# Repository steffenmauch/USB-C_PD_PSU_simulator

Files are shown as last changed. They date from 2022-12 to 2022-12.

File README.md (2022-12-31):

# USB-C_PD_PSU_simulator

USB-C PD power supply simulator based on STUSB4710 with CP2112 USB/I2C interface chip

### Introduction

- USB-C power delivery powers supply simulator based on STUSB4710
- can be used to simulated non conformant power supplies
- e.g. output different voltage than the one being negotiated
- manipulate offered contracts to simulate specific power supplies
- layout and schematic has been realized with KiCad 6
- correspondig software is written with python 3
- communication with STUSB4710 is realized with SiLabs 2112 USB to I2C/SMBUS interface chip

### Hardware Setup

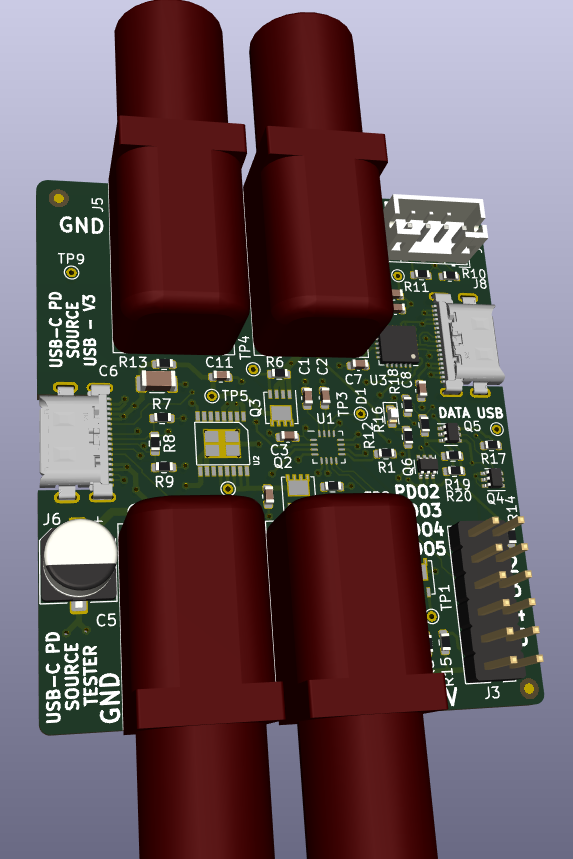
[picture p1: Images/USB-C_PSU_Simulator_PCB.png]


Find schematic as PDF [here](./ECAD/USB-C_PSU_Simulator.pdf)

### Usage
- install python3 if not already installed; e.g. https://winpython.github.io/ for Windows users
- download from www.silabs.com the driver containing the files 'SLABHIDDevice.*' and 'SLABHIDtoSMBus.*' (extension .dll for Windows)
- copy both files into 'Software' subdirectory
- execute e.g. 'python configSTUSB4710.py' in the 'Software' subdirectory
```
python configSTUSB4710.py
usage: configSTUSB4710.py [-h] [-r] [--setToleranceVBUS [0-15]] [--setPDO SETPDO [SETPDO ...]] [--printRDO] [--printPDO] [--printNVM] [--printToleranceVBUS] [--printVBUSControl] [--printPortStatus]
                          [--printSTUSBVersion] [-v]

Configure STUSB4710 for USB-C PD power supply simulation; (c) 12/2022 Steffen Mauch; MIT license

optional arguments:
  -h, --help            show this help message and exit
  -r, --resetSTUSB      reset STUSB4710 via command
  --setToleranceVBUS [0-15]
                        set additional VBUS tolerance in percent of STUSB4710
  --setPDO SETPDO [SETPDO ...]
                        modify PDO of STUSB4710; first argument selects #PDO;second argument voltage in [mv]; third argument current in [mA] e.g. 1 5000 2000 will set PDO1 to 5V and 2A
  --printRDO            shows actual settings requested data object (RDO) of STUSB4710
  --printPDO            shows actual settings power data object (PDO) of STUSB4710
  --printNVM            shows actual content of non volatile memory (NVM) of STUSB4710
  --printToleranceVBUS  get full VBUS tolerance in percent of STUSB4710 [incl. 5 percent default]
  --printVBUSControl    get VBUS control register of STUSB4710
  --printPortStatus     get port status register of STUSB4710
  --printSTUSBVersion   get version register of STUSB4710
  -v, --version         show version of python script
```
- show advertised src of USB-C PD
```
python configSTUSB4710.py --printPDO

PDO SRC#1:  PdoSink(voltage=5.0V, current=3.0A, fastRoleReqCur=0, dualRoleData=0, usbCommunicationsCapable=0, unconstrainedPower=1, higherCapability=0, dualRolePower=0, supply=Fixed, raw=0x0801912c)
PDO SRC#2:  PdoSink(voltage=9.0V, current=3.0A, fastRoleReqCur=0, dualRoleData=0, usbCommunicationsCapable=0, unconstrainedPower=0, higherCapability=0, dualRolePower=0, supply=Fixed, raw=0x0002d12c)
PDO SRC#3:  PdoSink(voltage=12.0V, current=3.0A, fastRoleReqCur=0, dualRoleData=0, usbCommunicationsCapable=0, unconstrainedPower=0, higherCapability=0, dualRolePower=0, supply=Fixed, raw=0x0003c12c)
PDO SRC#4:  PdoSink(voltage=15.0V, current=3.0A, fastRoleReqCur=0, dualRoleData=0, usbCommunicationsCapable=0, unconstrainedPower=0, higherCapability=0, dualRolePower=0, supply=Fixed, raw=0x0004b12c)
PDO SRC#5:  PdoSink(voltage=20.0V, current=2.25A, fastRoleReqCur=0, dualRoleData=0, usbCommunicationsCapable=0, unconstrainedPower=0, higherCapability=0, dualRolePower=0, supply=Fixed, raw=0x000640e1)
```

### Background information for STUSB4710
- 'dm00664189-the-stusb4500-software-programing-guide-stmicroelectronics.pdf'
- 'STUSB47xx_register_map_public.pdf'
- 'STSW-STUSB004 - Quick Start - v1.0.pdf'
- 'TNxxx - STUSB4500 NVM Description_V1.1.pdf' and 'TNxxx - STUSB4700 NVM Description.pdf' which is part of 'STSW-STUSB003' and STSW-STUSB004'

### Background information for CP2112
- API information can be found in 'AN496.pdf'

### License


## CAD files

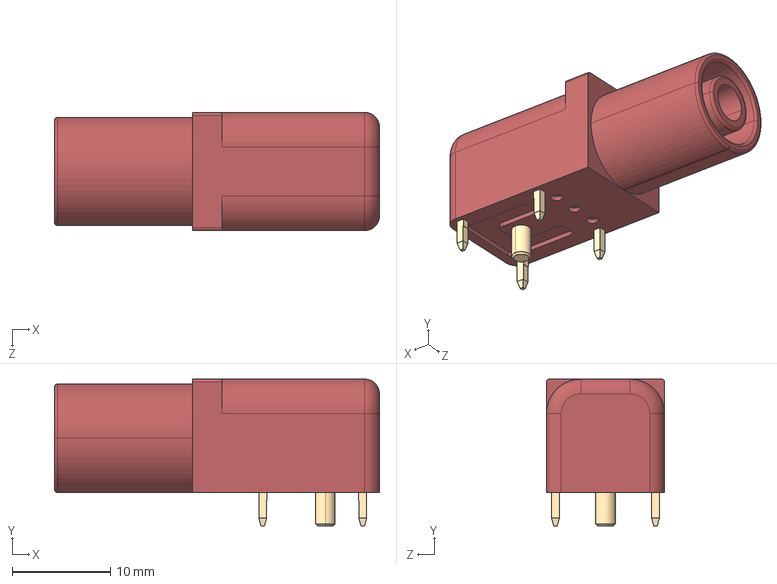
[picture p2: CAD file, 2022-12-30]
ECAD/CAD/FCR7350R--3DModel-STEP-56544.STEP
33.0 x 14.9 x 12.0 mm

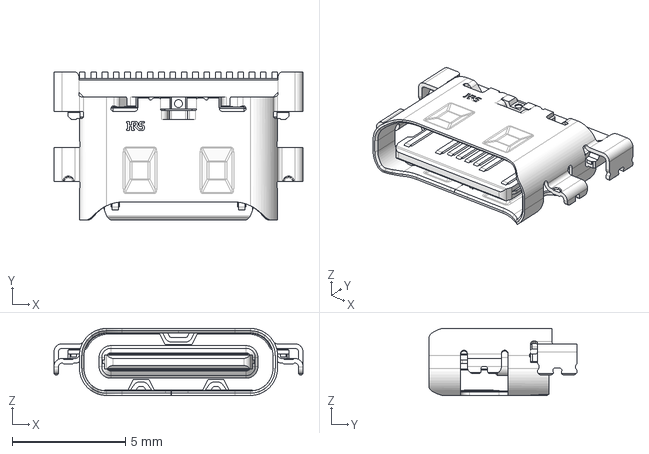
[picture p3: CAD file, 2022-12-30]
ECAD/CAD/CX90M-16P_4800513000_3D_STEP.stp
11.0 x 6.55 x 2.97 mm

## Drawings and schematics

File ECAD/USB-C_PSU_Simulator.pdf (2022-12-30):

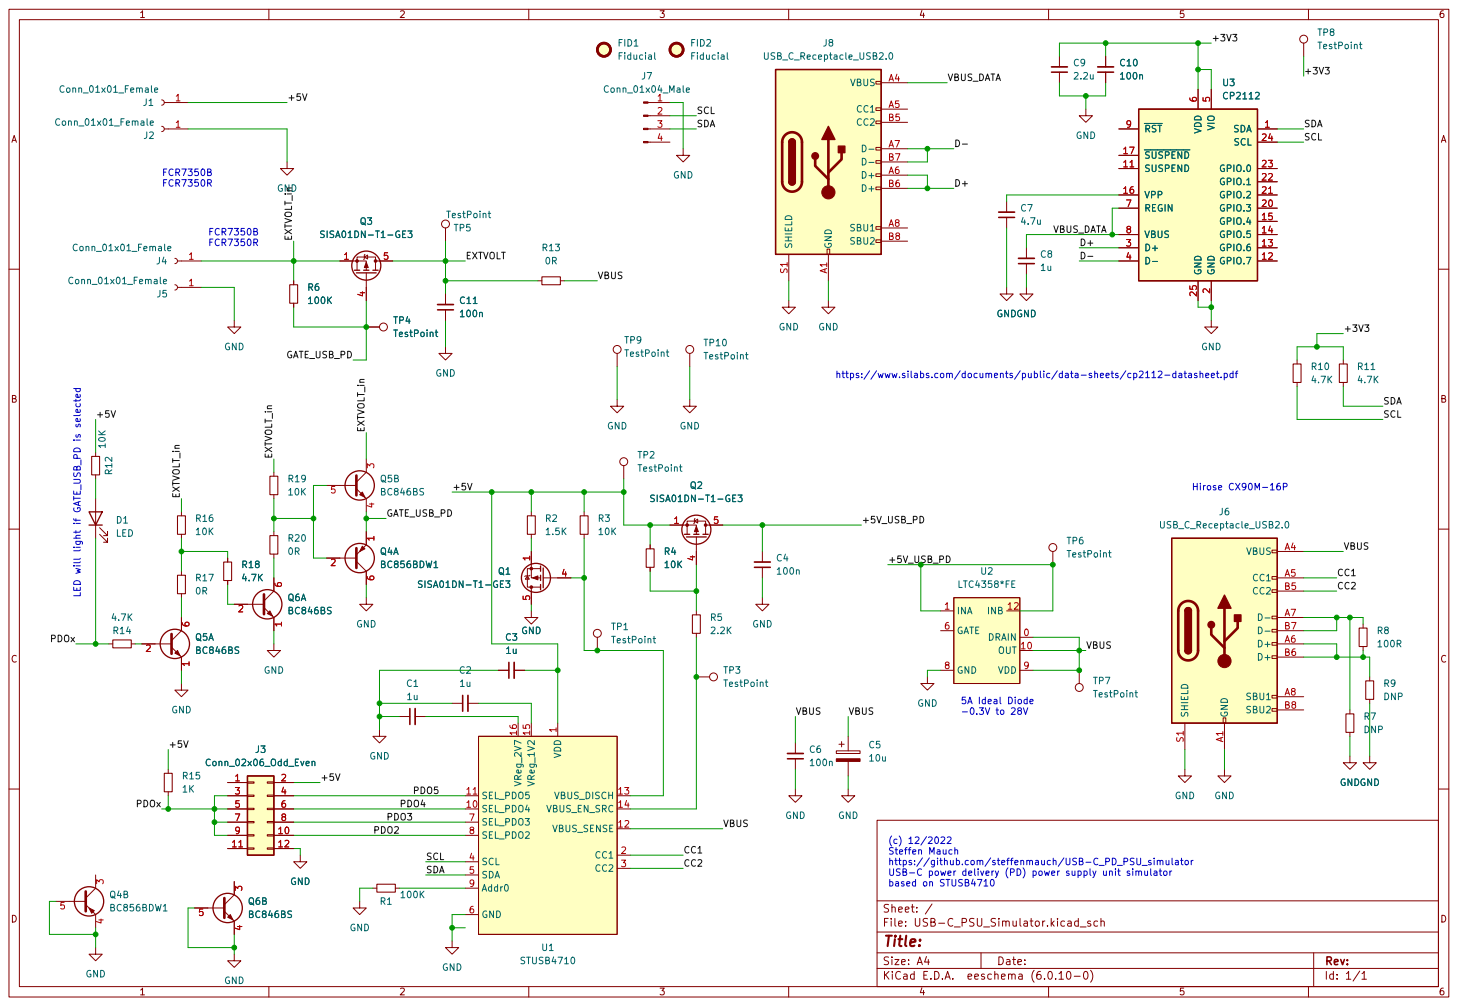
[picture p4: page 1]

2 GPIO.3 20 GPIO.2 21 GPIO.1 22 GPIO.0 23 SCL 24 GND 25 D+ 3 D- 4 VIO

https://www.silabs.com/documents/public/data-sheets/cp2112-datasheet.pdf

5 5 | 6 6
7 7 | 8 8

https://github.com/steffenmauch/USB-C_PD_PSU_simulator
USB-C power delivery (PD) power supply unit simulator based on STUSB4710

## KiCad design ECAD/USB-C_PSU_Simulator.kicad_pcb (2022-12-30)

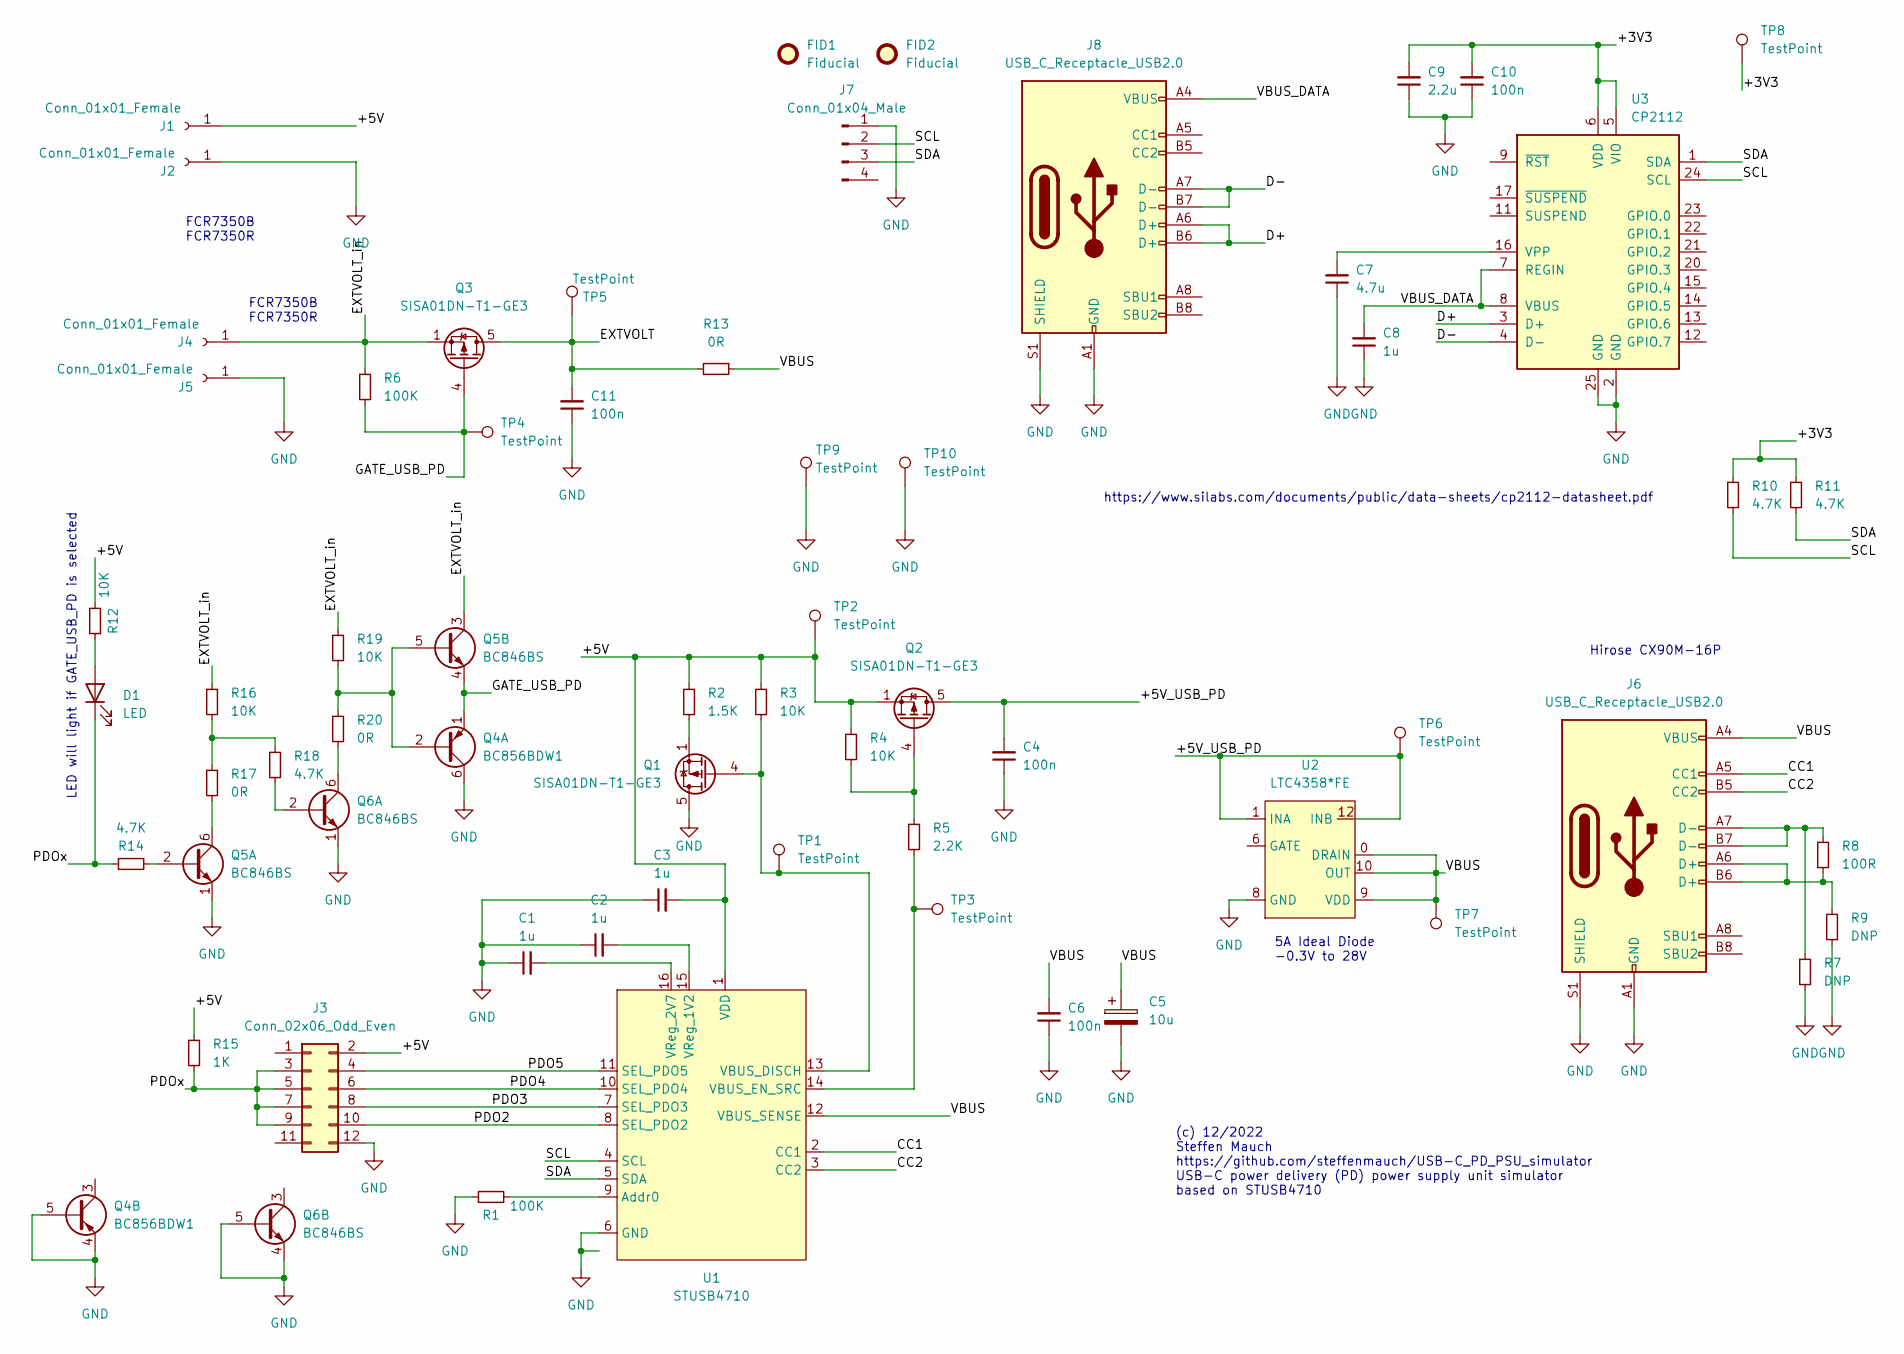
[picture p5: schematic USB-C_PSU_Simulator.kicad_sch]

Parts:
C1, C2, C3, C8: 1u; C_0603_1608Metric
C4, C10, C11: 100n; C_0603_1608Metric
C5: 10u; CP_Elec_6.3x5.4_Nichicon
C6: 100n; C_1206_3216Metric
C7: 4.7u; C_0603_1608Metric
C9: 2.2u; C_0603_1608Metric
D1: LED; LED_0603_1608Metric
FID1, FID2: Fiducial; Fiducial_1mm_Mask2mm
J1, J2, J4, J5: Conn_01x01_Female; FCR7350
J3: Conn_02x06_Odd_Even; PinHeader_2x06_P2.54mm_Vertical
J6, J8: USB_C_Receptacle_USB2.0; USB_C_Receptacle_Hirose_CX90M-16P
J7: Conn_01x04_Male; JST_PH_B4B-PH-K_1x04_P2.00mm_Vertical
Q1, Q2, Q3: SISA01DN-T1-GE3; Vishay_PowerPAK_1212-8_Single
Q4: BC856BDW1; SOT-363_SC-70-6
Q5, Q6: BC846BS; SOT-363_SC-70-6
R1, R6: 100K; R_0603_1608Metric
R2: 1.5K; R_0603_1608Metric
R3, R4, R12, R16, R19: 10K; R_0603_1608Metric
R5: 2.2K; R_0603_1608Metric
R7, R9: DNP; R_0603_1608Metric
R8: 100R; R_0603_1608Metric
R10, R11, R14, R18: 4.7K; R_0603_1608Metric
R13, R17, R20: 0R; R_0603_1608Metric
R15: 1K; R_0603_1608Metric
TP1, TP2, TP3, TP4, TP5, TP6, TP7, TP8, TP9, TP10: TestPoint; TestPoint_THTPad_D1.0mm_Drill0.5mm
U1: STUSB4710; QFN-16_3x3_Pitch0.5mm
U2: LTC4358*FE; 16-LeadPlasticTSSOP_ANALOG
U3: CP2112; QFN-24-1EP_4x4mm_P0.5mm_EP2.6x2.6mm

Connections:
/+3V3: C9.2, C10.2, R10.1, R11.1, TP8.1, U3.5 (VIO), U3.6 (VDD)
/+5V: C3.2, J1.1, J3.2, Q2.1 (S), Q2.2 (S), Q2.3 (S), R2.2, R3.2, R4.1, R12.2, R15.1, TP2.1, U1.1 (VDD)
/CC1: J6.A5 (CC1), U1.2 (CC1)
/CC2: J6.B5 (CC2), U1.3 (CC2)
/D+: J8.A6 (D+), J8.B6 (D+), U3.3 (D+)
/D-: J8.A7 (D-), J8.B7 (D-), U3.4 (D-)
/EXTVOLT: C11.2, Q3.5 (D), R13.2, TP5.1
/EXTVOLT_in: J4.1, Q3.1 (S), Q3.2 (S), Q3.3 (S), Q5.3 (C2), R6.1, R16.1, R19.1
/GATE_USB_PD: Q3.4 (G), Q4.1 (E1), Q5.4 (E2), R6.2, TP4.1
/PDO2: J3.10, U1.8 (SEL_PDO2)
/PDO3: J3.8, U1.7 (SEL_PDO3)
/PDO4: J3.6, U1.10 (SEL_PDO4)
/PDO5: J3.4, U1.11 (SEL_PDO5)
/PDOx: D1.1 (K), J3.3, J3.5, J3.7, J3.9, R14.2, R15.2
/SCL: J7.2, R10.2, U1.4 (SCL), U3.24 (SCL)
/SDA: J7.3, R11.2, U1.5 (SDA), U3.1 (SDA)
/VBUS: C5.1, C6.2, J6.A4 (VBUS), J6.A9 (VBUS), J6.B4 (VBUS), J6.B9 (VBUS), R13.1, TP7.1, U1.12 (VBUS_SENSE), U2.0 (DRAIN), U2.9 (VDD), U2.10 (OUT)
/VBUS_DATA: C8.2, J8.A4 (VBUS), J8.A9 (VBUS), J8.B4 (VBUS), J8.B9 (VBUS), U3.7 (REGIN), U3.8 (VBUS)
GND: C1.1, C2.1, C3.1, C4.1, C5.2, C6.1, C7.1, C8.1, C9.1, C10.1, C11.1, J2.1, J3.12, J5.1, J6.A1 (GND), J6.A12 (GND), J6.B1 (GND), J6.B12 (GND), J6.S1 (SHIELD), J7.1, J8.A1 (GND), J8.A12 (GND), J8.B1 (GND), J8.B12 (GND), J8.S1 (SHIELD), Q1.5 (D), Q4.4 (E2), Q4.5 (B2), Q4.6 (C1), Q5.1 (E1), Q6.1 (E1), Q6.4 (E2), Q6.5 (B2), R1.1, R7.2, R9.1, TP9.1, TP10.1, U1.6 (GND), U2.8 (GND), U3.2 (GND), U3.25 (GND)
IN: C4.2, Q2.5 (D), TP6.1, U2.1 (INA), U2.2 (IN), U2.3 (IN), U2.4 (IN), U2.12 (INB), U2.13 (INB), U2.14 (INB), U2.15 (INB), U2.16 (INB)
unnamed: C1.2, U1.16 (VReg_2V7)
unnamed: C2.2, U1.15 (VReg_1V2)
unnamed: C7.2, U3.16 (VPP)
unnamed: D1.2 (A), R12.1
unnamed: J6.A6 (D+), J6.B6 (D+), R8.2, R9.2
unnamed: J6.A7 (D-), J6.B7 (D-), R7.1, R8.1
unnamed: Q1.1 (S), Q1.2 (S), Q1.3 (S), R2.1
unnamed: Q1.4 (G), R3.1, TP1.1, U1.13 (VBUS_DISCH)
unnamed: Q2.4 (G), R4.2, R5.1
unnamed: Q5.2 (B1), R14.1
unnamed: Q4.2 (B1), Q5.5 (B2), R19.2, R20.1
unnamed: Q5.6 (C1), R17.2
unnamed: Q6.2 (B1), R18.2
unnamed: Q6.6 (C1), R20.2
unnamed: R1.2, U1.9 (Addr0)
unnamed: R5.2, TP3.1, U1.14 (VBUS_EN_SRC)
unnamed: R16.2, R17.1, R18.1

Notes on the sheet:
5A Ideal Diode -0.3V to 28V
Hirose CX90M-16P
https://www.silabs.com/documents/public/data-sheets/cp2112-datasheet.pdf
FCR7350B FCR7350R
LED will light if GATE_USB_PD is selected
(c) 12/2022 Steffen Mauch https://github.com/steffenmauch/USB-C_PD_PSU_simulator USB-C power delivery (PD) power supply unit simulator based on STUSB4710

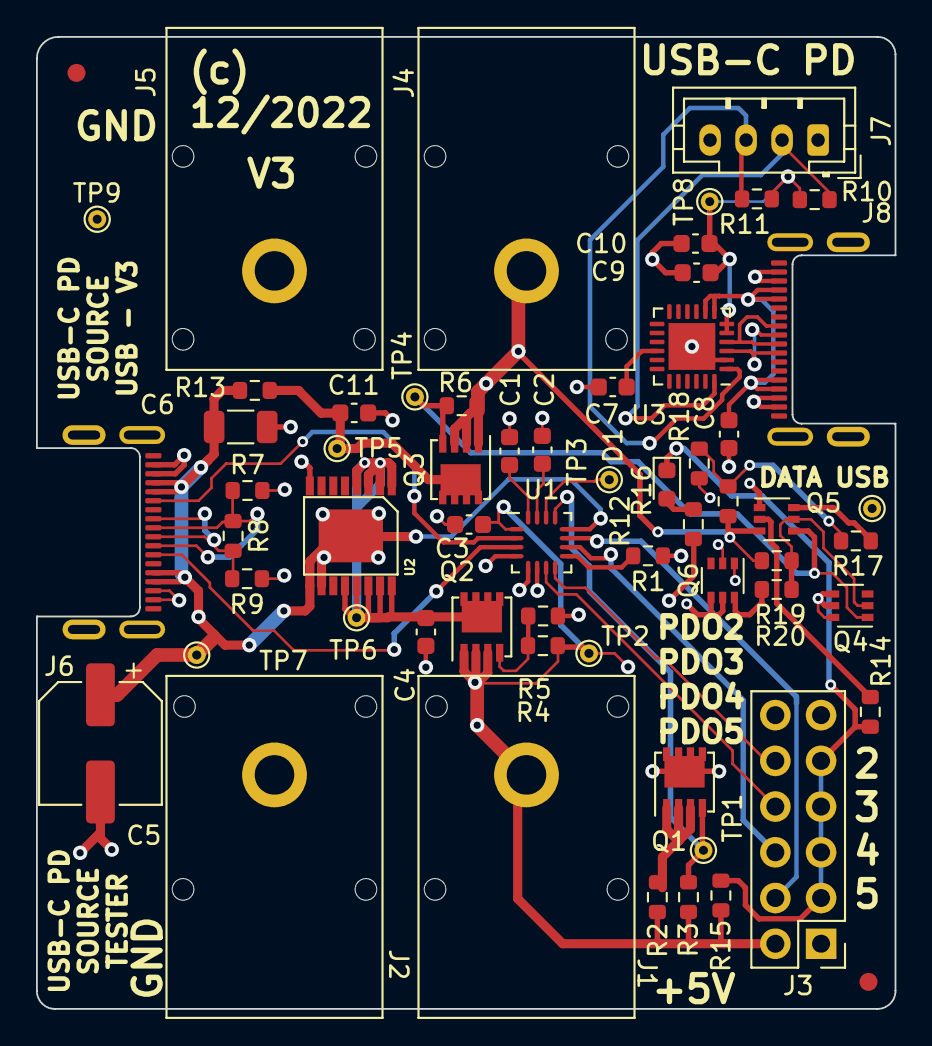
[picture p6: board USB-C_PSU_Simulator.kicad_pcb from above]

Board: 4 copper layers, 47.7 x 54.0 mm, 61 parts (0 on the bottom side), 37 nets.

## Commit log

2022-12-30 initial commit with schematic and board + LTSpice simulation of transistor stage
    [CX90M-16P_4800513000_3D_STEP.stp, FCR7350R--3DModel-STEP-56544.STEP, USB-C_PSU_Simulator.kicad_pcb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]
2022-12-31 fixed naming and indexing of PDOs to match datasheet and naming on PCB

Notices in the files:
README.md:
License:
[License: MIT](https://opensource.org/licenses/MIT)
